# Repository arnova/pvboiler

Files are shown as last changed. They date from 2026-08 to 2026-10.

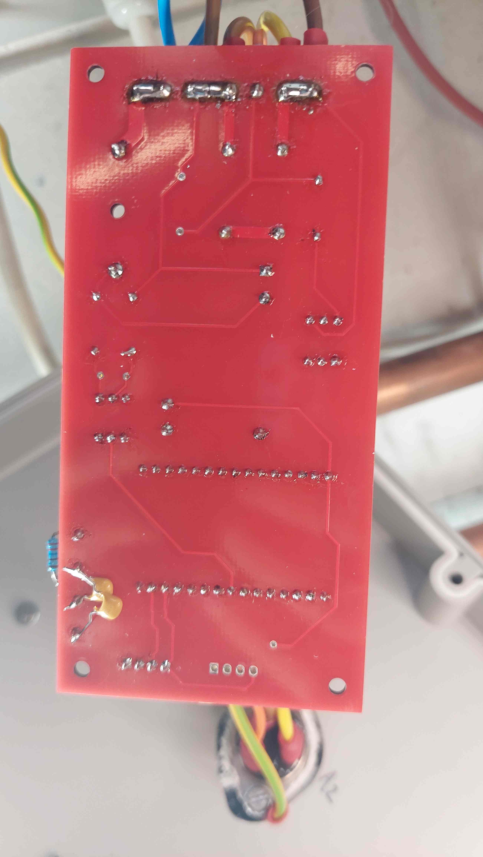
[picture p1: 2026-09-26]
pictures/pvboiler_pcb_rev0_back.jpg

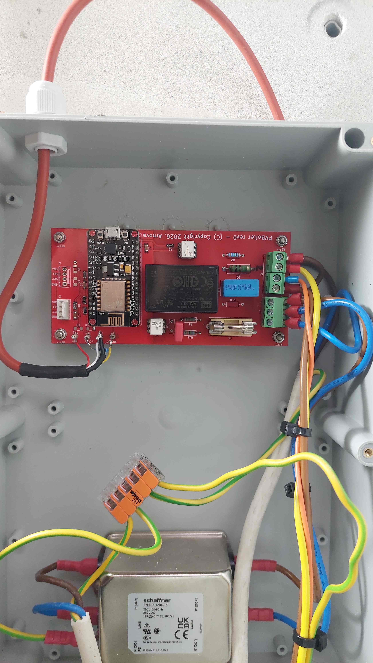
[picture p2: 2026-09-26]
pictures/pvboiler_pcb_rev0_in_enclosure.jpg

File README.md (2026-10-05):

# Open-source ESP PV-Boiler Controller

> ⚠️ **WARNING: HAZARDOUS VOLTAGES**
>
> This project is provided "as-is" and is to be used entirely at your own risk! The hardware is connected to the mains and involves voltages that may be lethal. Only build, install and service it if you are qualified to work on mains equipment, and always disconnect it from the mains before opening the enclosure.
>
> - The ESP/low-voltage side of the controller is galvanically isolated from the mains. Nevertheless, treat everything as live and dangerous!
> - Mount the controller in a closed plastic enclosure and earth the heatsink properly to the mains ground.
> - Only connect the controller to a correctly fused circuit.
> - The boiler's own thermostat and thermal cutoff must remain in the heating circuit. This controller is not a substitute for over-temperature protection!

This project is a complete hardware, firmware & software solution to turn your "dumb" electronic domestic hot water boiler into a smart **PV-Boiler**. It aims to optimize the amount of surplus solar electricity that can be stored in a boiler as hot water using as little grid power as possible.

Most other solutions use SSR modules for power control. This design uses a (BTA25/BTA40) **triac** for power control to enable **phase-angle control**, which allows for more accurate power control than with a normal SSR.

The hardware was designed using **KiCAD**, and the software uses **MQTT** for communication, targeted to be used with **Home Assistant**. The hardware and firmware were developed for a NodeMCU v2 (Amica) ESP8266 module, but should in principle work with any ESP8266 or ESP32 board. Obviously, ESP boards with alternative form factors and/or pinouts cannot be directly fitted on the PCB but should be connected using wires, and you may need to modify platformio.ini and the GPIO definitions in include/system.h for your specific ESP board.

## Features

- Home Assistant (MQTT) support
- Phase angle control (default) or SSR dim style
- Configuration via USB serial connection or network terminal connection (port 8000)
- OTA updates (e.g. via PlatformIO)
- Operating modes: automatic power budget mode (using e.g. P1/HA information), (manual) power percentage mode, boost mode (100% power) and off mode. The mode can be dynamically changed using MQTT
- Support for an optional one-wire DS18B20 temperature sensor (probe) for sensing the boiler's internal temperature
- Support for an optional OLED 128×64 screen to display output power/percentage and connection status
- The controller has a network watchdog. If there hasn't been any MQTT traffic to the controller for a while (e.g. when the network fails), the output will automatically decrease to 0% instead of being stuck on the last value. This behaviour can be disabled/configured with the `netwdt` and `netwdr` commands.

## Planned features & improvements

- Automatic legionella prevention using an external one-wire temperature sensor. Currently boost mode can be used for external (e.g. using Home Assistant) legionella prevention control until implemented in firmware
- Improve control loop for budget logic mode
- Standalone support to directly interface with MQTT P1 providers like DSMR Reader
- New PCB design to fit a (dual-core) ESP32-DevKit module

## Known issues

- During development it turned out that due to the ESP8266's single-core architecture WiFi interferes with accurate interrupt timing, causing problems with zero-cross detection and triac gate firing. Mitigations are in place but they can't completely fix the issue. Therefore for new designs it's recommended to use an ESP board with a dual-core ESP32-S3, ESP32-WROOM or ESP32-Wrover. Note that single-core ESP32 variants (e.g. ESP32-C3, ESP32-S2) share the ESP8266's limitation.

## Electromagnetic compatibility

Phase-angle control inherently generates harmonics and electromagnetic interference, because the triac switches the load on part-way through each mains half-cycle. The design includes an RC snubber across the triac and a 2-stage mains filter to limit this. Although such mains filters are expensive, do not omit them: consider the filter mandatory. Depending on your country and installation, regulations on conducted emissions and flicker (e.g. the EN 61000-3 series in the EU) may still apply to the complete installation, so check them before putting the device into permanent use.

## Hardware Assembly Hints

1. In the pictures-folder of this project you can find photos of my assembled enclosure which can be used as a guideline to build your own device
2. Use a sufficiently sized heatsink with a little thermal compound for mounting the BTA-triac. Generally it is recommended to use a heatsink with a thermal resistance better than 1.0 °C/W when using a ~2500 W boiler. Don't forget to connect the heatsink to the mains ground for safety! You should also use triacs with an electrically insulated tab, like the BTA-type triacs in the design
3. Around some power traces the mask has been intentionally left out. You should solder these traces with extra solder to reduce the power losses due to trace resistance
4. It is recommended to use 1.5 mm² flexible wires for internal wiring
5. When using a one-wire DS18B20 temperature sensor (probe) there are a few things you must adhere to make it work properly. Its supply should be connected to the board's +5V (not +3.3V), and the cable's ground shield should be connected to the (digital) low-voltage ground (NOT the mains ground) of the board. Most (sealed) temperature probes use a metal probe housing which is connected to the cable shield. Since this may short to the mains ground and introduce (switching) noise into the system, it should be isolated. The easiest way to accomplish this is using some shrink-tube
6. The electronics are designed for ~230 VAC grids. For other (lower) grid voltages some resistors (R1, R2, R11) need to be modified
7. The controller can only be connected directly to the normal mains connections of "dumb" hot water boilers. Boilers featuring any kind of (digital) electronics (except for an analog thermostat) require a modification of the boiler's internal wiring, see [Boilers with built-in electronics](#boilers-with-built-in-electronics)

## Boilers with built-in electronics

For boilers with (digital) electronics the controller cannot be connected to the boiler's normal mains connections. Instead, the controller must be placed in series with the boiler's heating element. This requires modifying the boiler's internal wiring:

1. Disconnect the boiler from the mains and make sure it cannot be switched on accidentally.
2. Of the 2 wires of the (internal) heating element(s), identify the one that is connected to the (safety) thermostat. This wire, and therefore the thermostat, must remain untouched.
3. Cut the other wire (the one NOT connected to the thermostat) in two. Connect only the end that goes to the heating element to the controller's TRIAC-L terminal.
4. Power the controller in one of these ways:
   - **Recommended: from the cut wire.** Connect the other cut end (the one coming from the boiler) to the controller's MAINS-L terminal, and connect the controller's MAINS-N terminal to the boiler's N (the connection the thermostat-side element wire returns to). The controller then only needs this one additional N connection. Because the controller takes its L from the same wire that used to feed the element, the L/N polarity pitfall of the separate feed option is avoided, which makes this option much more fool-proof. The cut end goes directly to the boiler's L input and is therefore permanently live; verify this with a multimeter before connecting.
   - **Separate feed.** Connect the controller's MAINS-L and MAINS-N terminals to the boiler's mains L and N, and properly insulate the unused cut end. Make sure the boiler's mains L/N connections are such that the controller's MAINS-L is the same "L" that used to feed the cut wire. Otherwise you create a short between the mains N and L.

Wiring diagram for the recommended power option

Things to be aware of:

- The separate feed option is only suitable for a fixed (hard-wired) installation with verified polarity. Do **not** use it with a reversible plug (e.g. Schuko) where L and N are undefined. Always verify L and N with a multimeter.
- The boiler's own electronics may react unexpectedly to the modification (e.g. by reporting a fault when the element is not powered). This is boiler-dependent.
- Modifying a boiler's internal wiring may void its warranty and, depending on your country, may need to be performed by a qualified electrician.

Only do this when you have sufficient confidence you understand what you are doing!

## First Time Use

1. Flash the ESP firmware using PlatformIO. The initial flash needs to be performed using the USB serial connection, with one of the `usb-xxxxx` (`usb-esp8266` or `usb-esp32`) PlatformIO-environments: `pio run -e usb-xxxxx -t upload`. You may need to customize `platform` and `board` in your `platformio.ini` for your specific ESP board first.
2. After the initial flash, future firmware updates can be done over-the-air (OTA) with one of the `ota-xxxxx` (`ota-esp8266` or `ota-esp32`) PlatformIO-environments: `pio run -e ota-xxxxx -t upload`. Note that you *may* need to substitute the controller's IP address for `pvboiler.local` in `upload_port` of the relevant `ota-xxxxx` environment in case mDNS is not available in your network (or it's failing somehow).
3. Connect to the microcontroller's terminal interface, either via the USB connection or a socket connection to the device's IP at port 8000, using a terminal program (e.g. PuTTY). The network terminal is plain-text and also gives access to the stored WiFi and MQTT credentials, so only use it on a network you trust.
4. In the command terminal, `help` (+ `Enter`) will show all available commands with their descriptions. Initially, these operations must be performed:
   - Reset all settings to default with the `factoryreset`-command.
   - Set your WiFi network SSID with the `ssid`-command, providing the name of your network as an argument.
   - Set your WiFi network password with the `pass`-command, providing your network's security password as an argument. You may provide a zero-length value when your network requires no password.
   - Set your MQTT server IP with the `serverip`-command, providing the server IP as an argument.
   - Set your MQTT server username with the `mqttuser`-command. You may provide a zero-length value when your server requires no username.
   - Set your MQTT server password with the `mqttpass`-command. You may provide a zero-length value when your server requires no password.
   - Set boiler power rating with the `boiler`-command, providing the power rating of your boiler as an argument (the factory default is 2500 W).

> **Notes**
>
> - Only change other settings when you understand what they do!
> - When using budget logic mode, you must regularly (at least at 5-second intervals is recommended) tell the PvBoiler controller how much "budget" (= excess solar PV electricity) is available, e.g. from Home Assistant. A sample automation for Home Assistant can be found in the `home assistant` folder.

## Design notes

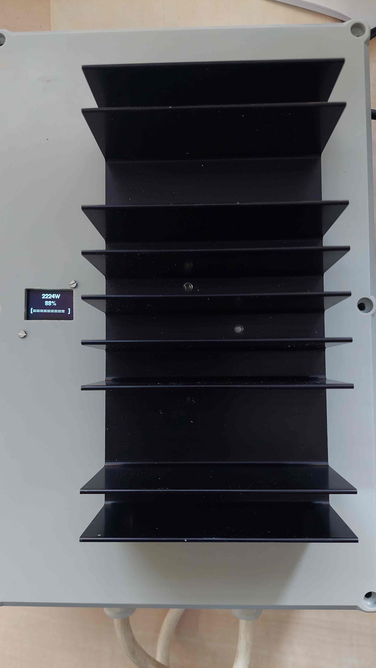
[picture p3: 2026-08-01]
pictures/pvboiler_outside.jpg

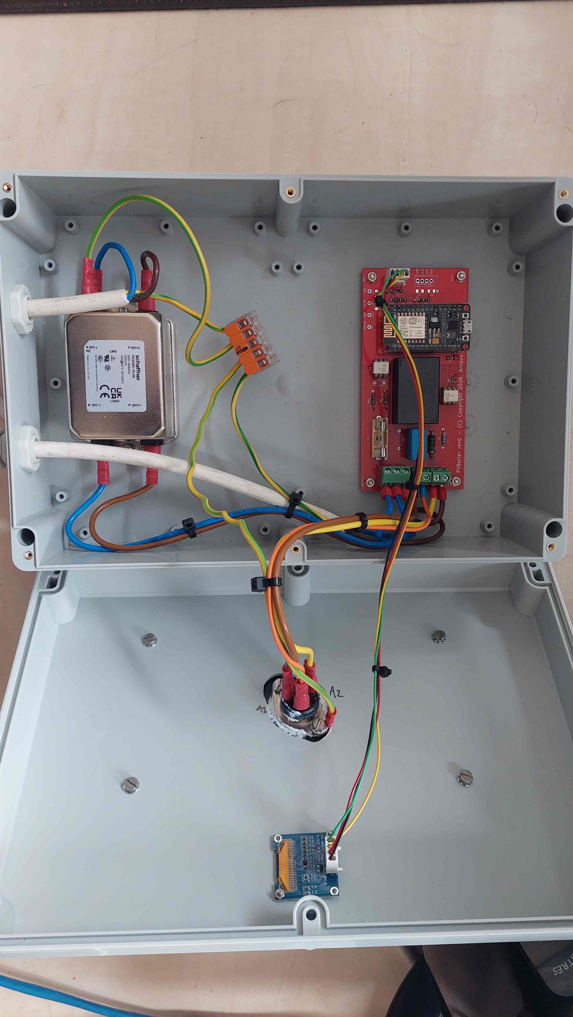
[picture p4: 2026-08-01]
pictures/pvboiler_inside2.jpg

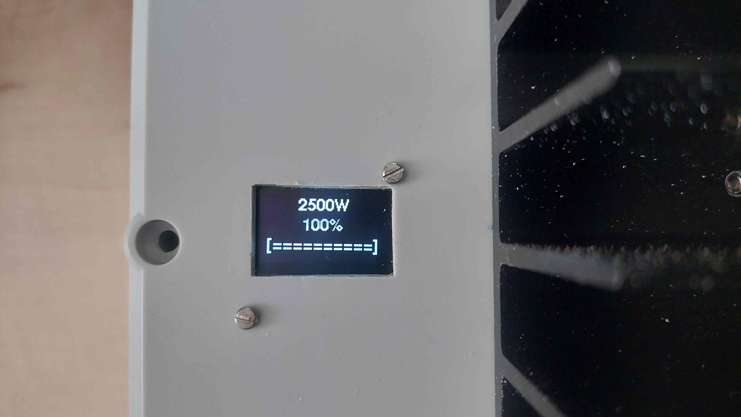
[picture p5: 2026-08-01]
pictures/pvboiler_oled.jpg

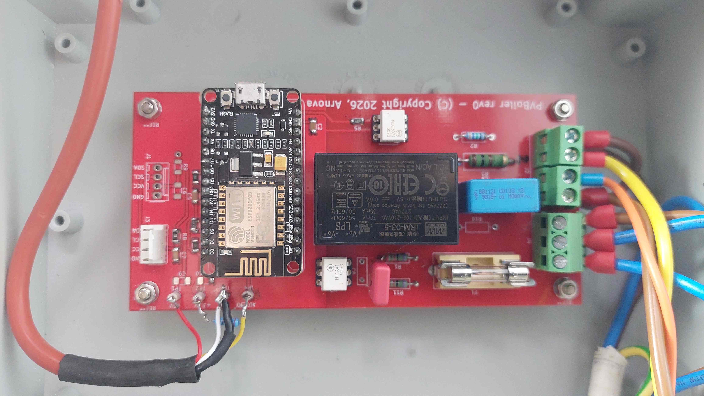
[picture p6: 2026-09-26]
pictures/pvboiler_pcb_rev0_front.jpg

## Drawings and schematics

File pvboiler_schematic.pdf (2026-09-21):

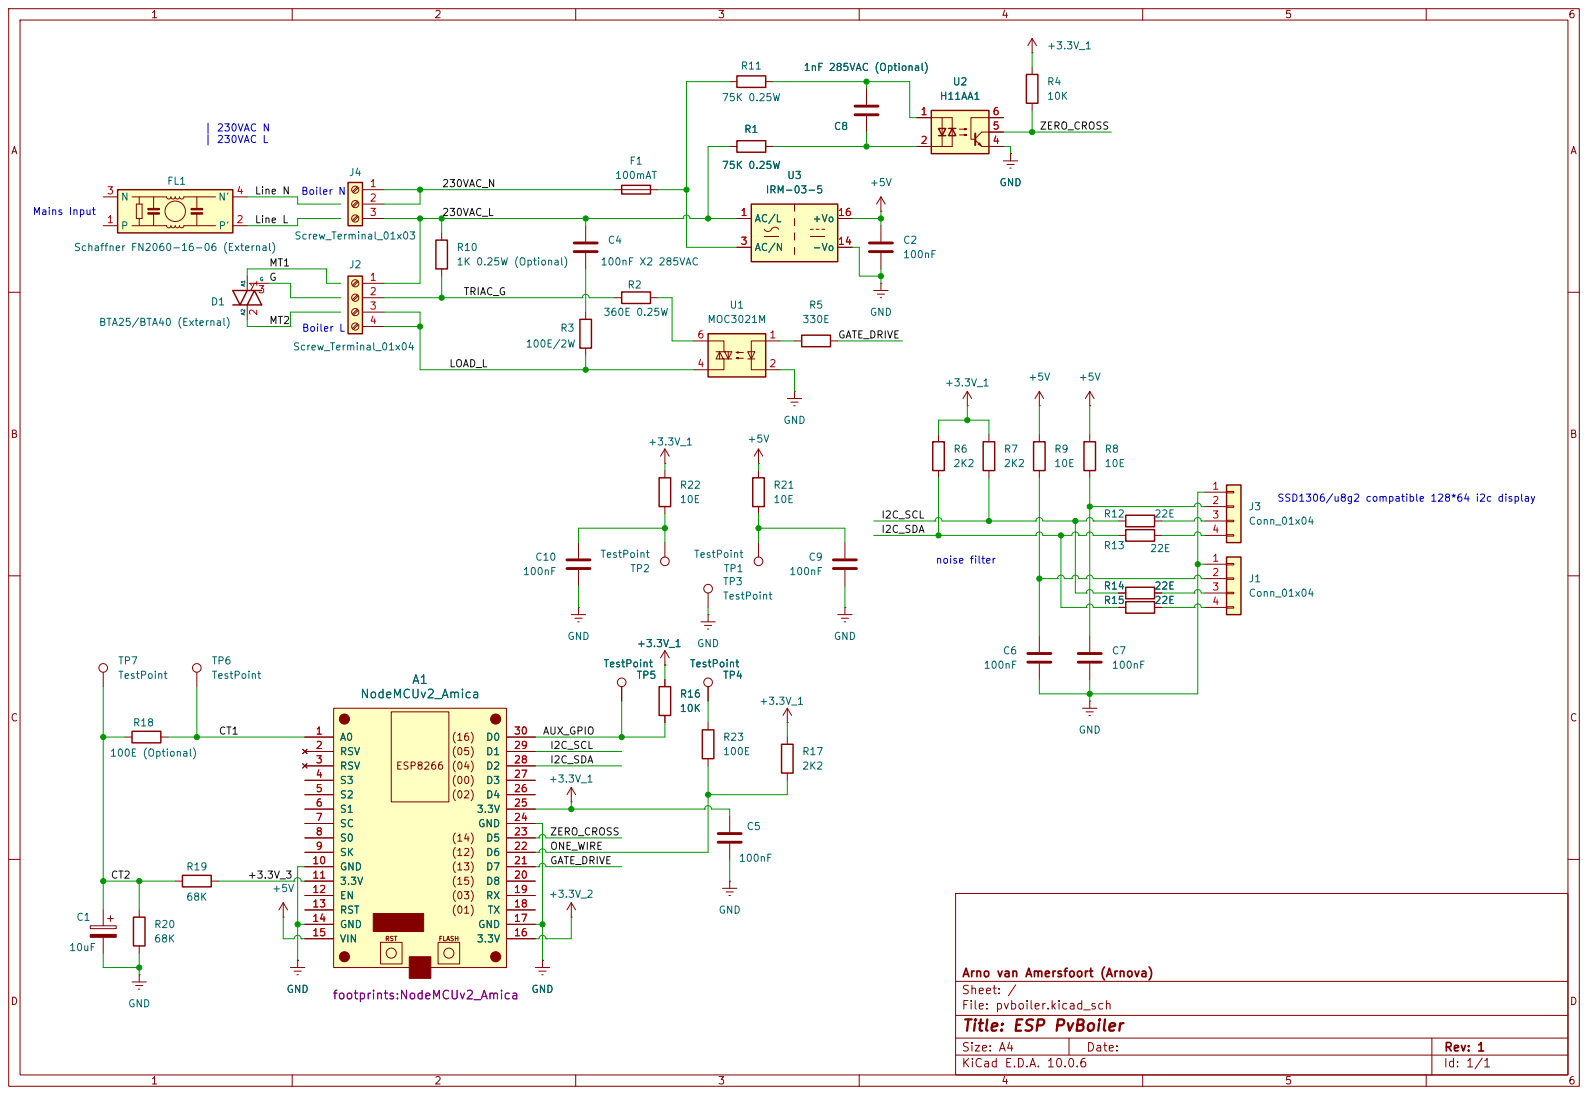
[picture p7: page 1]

Arno van Amersfoort (Arnova) +3.3V_2

Size: A4 | Rev: 1
KiCad E.D.A. 10.0.6 | Id: 1/1

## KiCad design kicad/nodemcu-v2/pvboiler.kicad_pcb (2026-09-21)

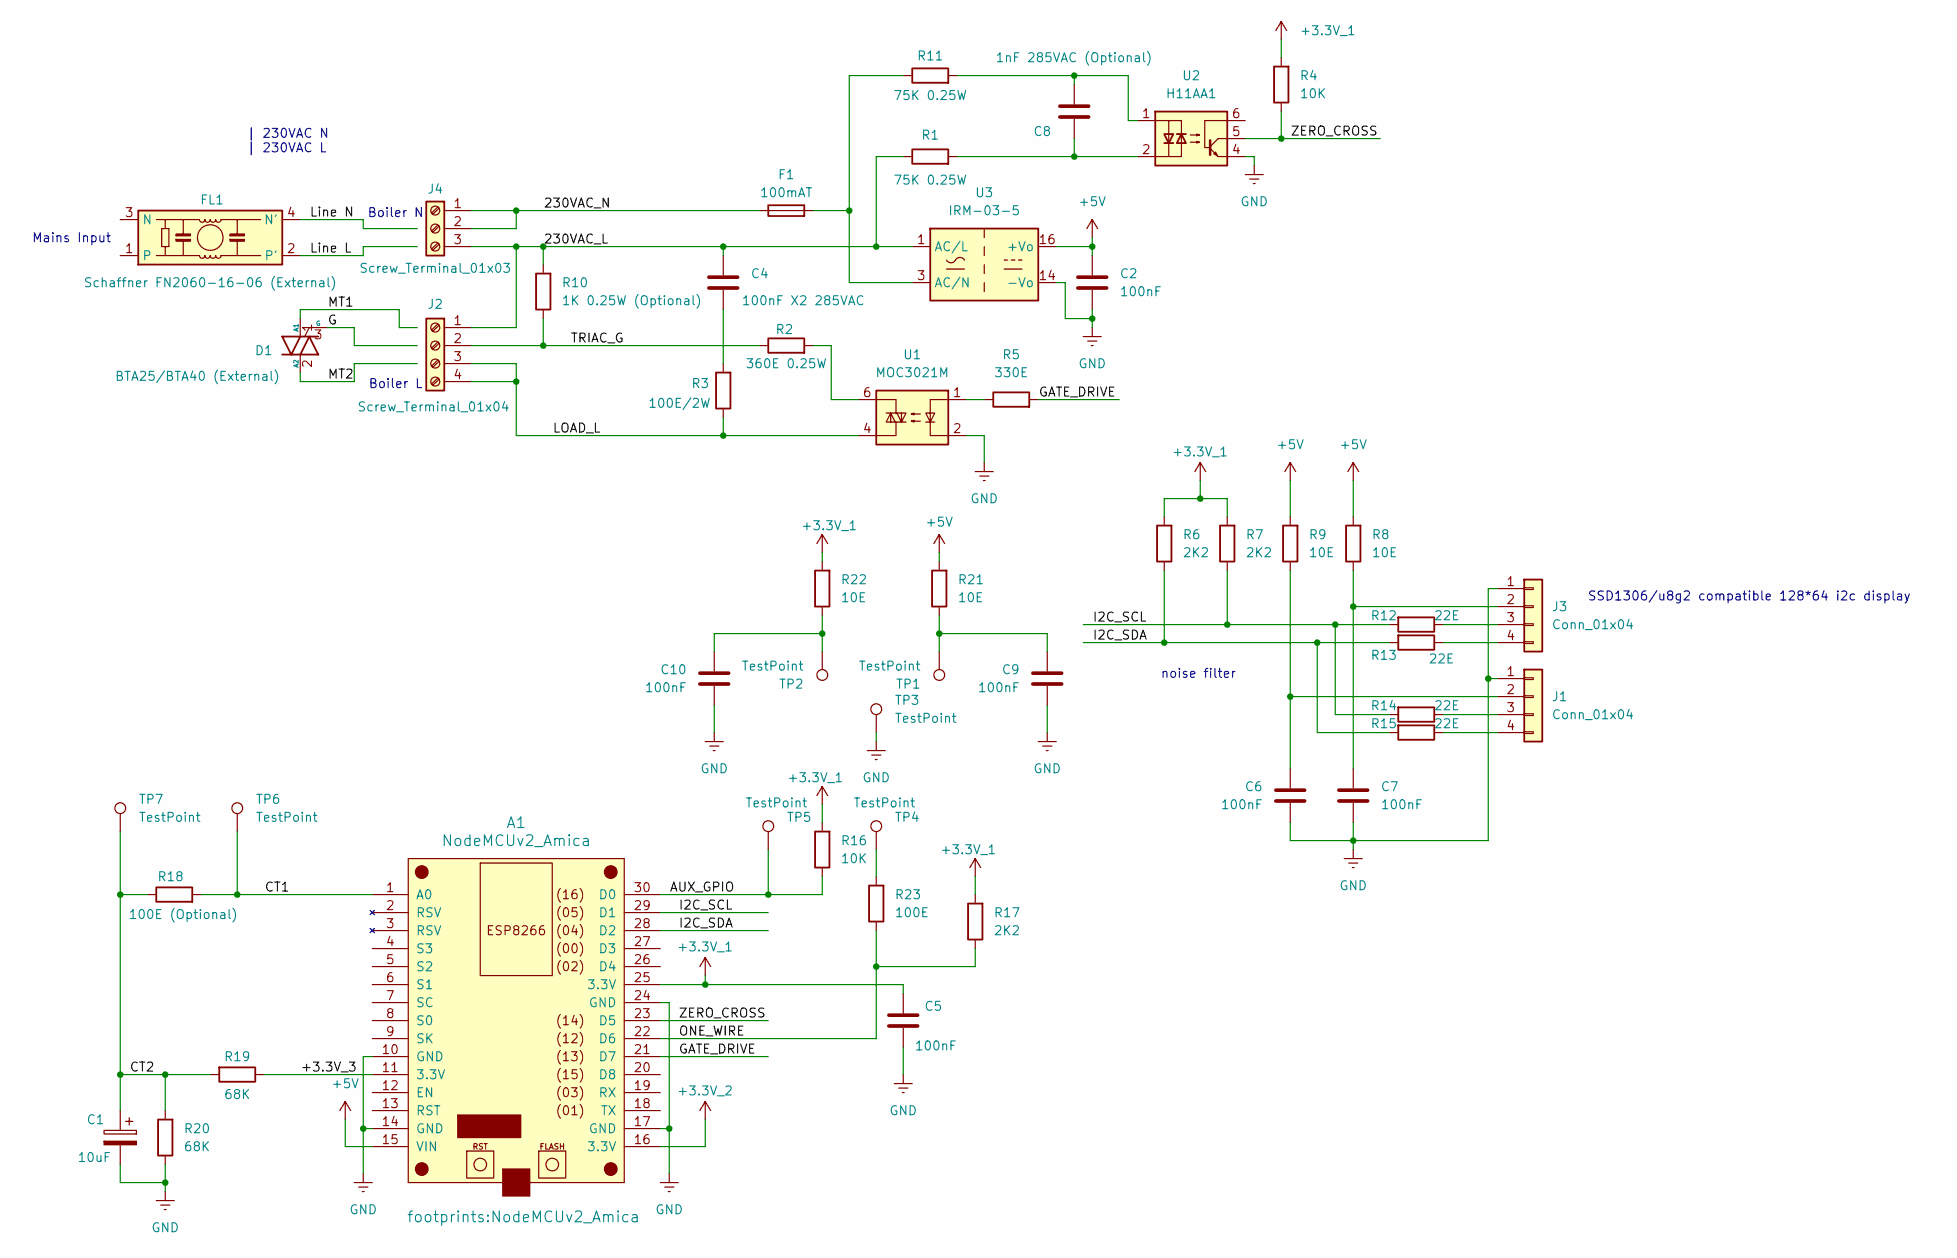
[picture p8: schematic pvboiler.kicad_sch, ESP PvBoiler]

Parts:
A1: NodeMCUv2_Amica
C1: 10uF; CP_EIA-3216-18_Kemet-A_HandSolder
C2, C5, C6, C7, C9, C10: 100nF; C_1206_3216Metric_Pad1.33x1.80mm_HandSolder
C4: 100nF X2 285VAC; C_Rect_L18.0mm_W8.0mm_P15.00mm_FKS3_FKP3
C8: 1nF 285VAC (Optional); C_Rect_L10.0mm_W4.0mm_P7.50mm_MKS4
D1: BTA25/BTA40 (External); PLCC-44_16.6x16.6mm_P1.27mm
F1: 100mAT; Fuseholder_Cylinder-5x20mm_Schurter_0031_8201_Horizontal_Op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
FL1: Schaffner FN2060-16-06 (External); Filter_FILTERCON_1FPxx
J1, J3: Conn_01x04; Molex_KK-254_AE-6410-04A_1x04_P2.54mm_Vertical
J2: Screw_Terminal_01x04; TerminalBlock_Phoenix_MKDS-1,5-4-5.08_1x04_P5.08mm_Horizont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
J4: Screw_Terminal_01x03; TerminalBlock_Phoenix_MKDS-1,5-3-5.08_1x03_P5.08mm_Horizont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
R1, R11: 75K 0.25W; R_Axial_DIN0207_L6.3mm_D2.5mm_P10.16mm_Horizontal
R2: 360E 0.25W; R_Axial_DIN0207_L6.3mm_D2.5mm_P10.16mm_Horizontal
R3: 100E/2W; R_Axial_DIN0414_L11.9mm_D4.5mm_P15.24mm_Horizontal
R4, R16: 10K; R_1206_3216Metric
R5: 330E; R_1206_3216Metric
R6, R7, R17: 2K2; R_1206_3216Metric
R8, R9, R21, R22: 10E; R_1206_3216Metric
R10: 1K 0.25W (Optional); R_Axial_DIN0207_L6.3mm_D2.5mm_P10.16mm_Horizontal
R12, R13, R14, R15: 22E; R_1206_3216Metric
R18: 100E (Optional); R_1206_3216Metric
R19, R20: 68K; R_1206_3216Metric
R23: 100E; R_1206_3216Metric
TP1, TP2, TP3, TP4, TP5, TP6, TP7: TestPoint; TestPoint_THTPad_D2.5mm_Drill1.2mm
U1: MOC3021M; DIP-6_W7.62mm
U2: H11AA1; DIP-6_W7.62mm
U3: IRM-03-5; Converter_ACDC_MeanWell_IRM-03-xx_THT

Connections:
+3.3V_1: A1.25 (3.3V), C5.1, R4.2, R6.2, R7.2, R16.2, R17.2, R22.2
+3.3V_2: A1.16 (3.3V)
+5V: A1.15 (VIN), C2.1, R8.2, R9.2, R21.2, U3.16 (+Vo)
/230VAC_L: C4.2, J2.1, J4.3, R1.1, R10.2, U3.1 (AC/L)
/230VAC_N: F1.1, J4.1, J4.2
/+3.3V_3: A1.11 (3.3V), R19.1
/AUX_GPIO: A1.30 (D0), R16.1, TP5.1 (1_1)
/CT1: A1.1 (A0), R18.2, TP6.1 (1_1)
/CT2: C1.1, R18.1, R19.2, R20.2, TP7.1 (1_1)
/GATE_DRIVE: A1.21 (D7), R5.2
/I2C_SCL: A1.29 (D1), R7.1, R12.2, R14.2
/I2C_SDA: A1.28 (D2), R6.1, R13.2, R15.2
/LOAD_L: J2.3, J2.4, R3.1, U1.4
/ONE_WIRE: A1.22 (D6), R17.1, R23.1
/TRIAC_G: J2.2, R2.1, R10.1
/ZERO_CROSS: A1.23 (D5), R4.1, U2.5
GND: A1.10 (GND), A1.14 (GND), A1.17 (GND), A1.24 (GND), C1.2, C2.2, C5.2, C6.2, C7.2, C9.2, C10.2, J1.1, J3.1, R20.1, TP3.1 (1_1), U1.2, U2.4, U3.14 (-Vo)
unnamed: C4.1, R3.2
unnamed: C8.1, R11.2, U2.1
unnamed: C8.2, R1.2, U2.2
unnamed: C9.1, R21.1, TP1.1 (1_1)
unnamed: C10.1, R22.1, TP2.1 (1_1)
unnamed: C6.1, J1.2, R9.1
unnamed: J1.3, R14.1
unnamed: J1.4, R15.1
unnamed: C7.1, J3.2, R8.1
unnamed: J3.3, R12.1
unnamed: J3.4, R13.1
unnamed: R2.2, U1.6
unnamed: R5.1, U1.1
unnamed: R23.2, TP4.1 (1_1)
unnamed: F1.2, R11.1, U3.3 (AC/N)

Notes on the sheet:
SSD1306/u8g2 compatible 128*64 i2c display
| 230VAC N | 230VAC L
Boiler N
noise filter
Boiler L
Mains Input

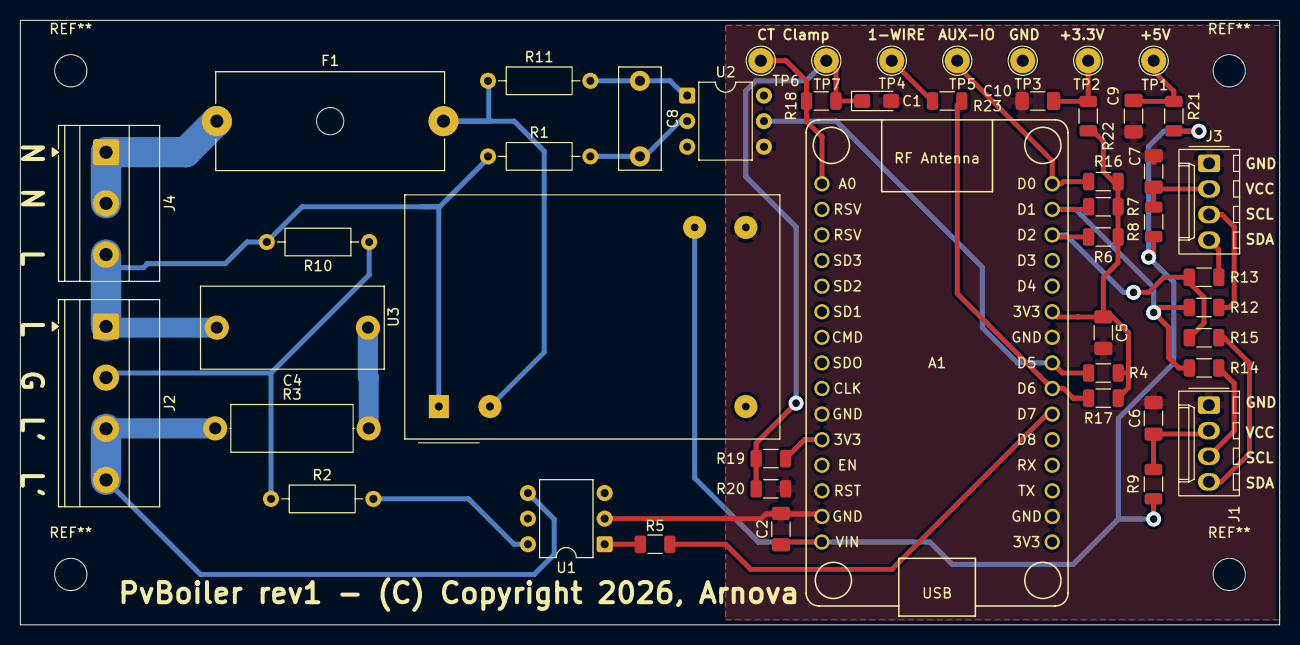
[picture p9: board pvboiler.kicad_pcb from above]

Board: 2 copper layers, 125.0 x 60.0 mm, 48 parts (0 on the bottom side), 31 nets.

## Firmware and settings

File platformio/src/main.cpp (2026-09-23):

/*
  ESP PV-Boiler - ESP Controlled PV Boiler
  Last update: September 21, 2026
  (C) Copyright 2026 by Arno van Amersfoort
  Web                   : https://github.com/arnova/pvboiler
  Email                 : a r n o DOT v a n DOT a m e r s f o o r t AT g m a i l DOT c o m
                          (note: you must remove all spaces and substitute the @ and the . at the proper locations!)
  ----------------------------------------------------------------------------------------------------------------------
  This program is free software; you can redistribute it and/or
  modify it under the terms of the GNU General Public License
  version 2 as published by the Free Software Foundation.

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
  You should have received a copy of the GNU General Public License
  along with this program; if not, write to the Free Software
  Foundation, Inc., 59 Temple Place - Suite 330, Boston, MA  02111-1307, USA.
  ---------------------------------------------------------------------------------------------------------------------- 
*/

#include <Arduino.h>
#include <EEPROM.h>

#include "Terminal.h"
#include "util.h"
#include "App.h"
#include "system.h"

// Application global instance
CApp g_app;

// Interrupt generated when crossing zero in either direction
void IRAM_ATTR ZeroCrossISR()
{
  g_app.ZeroCrossHandler();
}


// Timer interrupt for triggering triac gate
void IRAM_ATTR TriacTimerISR()
{
  g_app.TriacGateHandler();
}


void MqttCallback(char* topic, byte *payload, const unsigned int length)
{
  const size_t iLen = strlen(g_app.GetNetwork().GetHostName());
  if (strncmp(topic, g_app.GetNetwork().GetHostName(), iLen) != 0 ||
      strlen(topic) < iLen + 2)
    return; // Hostname mismatch or length too small

#ifdef MQTT_DEBUG
  CTerminal::println("-------new message from broker-----");
  CTerminal::print("topic: ");
  CTerminal::println(topic);
  CTerminal::print("data: ");
  for (unsigned int i = 0; i < length; i++)
  {
    CTerminal::print((char) payload[i]);
  }
  CTerminal::println("");
#endif
  //float fVal;
  //const bool bValidFloat = BytesToFloat(payload, length, fVal);

  int32_t iVal;
  const bool bValidInt = bytes_to_int32(payload, length, &iVal);

  char strVal[32] = { 0 };
  memcpy(strVal, payload, (length < sizeof(strVal)) ? length : sizeof(strVal) - 1);

  // Get rid of host prefix
  char* subTopic = topic + iLen;

  if (STRIEQUALS(subTopic, "/" MQTT_SET_POWER_BUDGET "/set"))
  {
    if (bValidInt)
    {
      g_app.GetPvBoiler().SetPowerBudget(iVal);
    }
    else
    {
      CMqttClient::PrintDataError();
    }
  }
  else if (STRIEQUALS(subTopic, "/" MQTT_SET_POWER_PERCENTAGE "/set"))
  {
    if (bValidInt && iVal >=0 && iVal <= 100)
    {
      g_app.GetPvBoiler().SetPowerPercentage(iVal);
    }
    else
    {
      CMqttClient::PrintDataError();
    }
  }
  if (STRIEQUALS(subTopic, "/" MQTT_SET_MODE "/set"))
  {
    if (strcasecmp(strVal, "Budget") == 0)
    {
      g_app.GetPvBoiler().SetMode(CPvBoiler::MODE_BUDGET);
    }
    else if (strcasecmp(strVal, "Percentage") == 0)
    {
      g_app.GetPvBoiler().SetMode(CPvBoiler::MODE_PERCENT);
    }
    else if (strcasecmp(strVal, "Off") == 0)
    {
      g_app.GetPvBoiler().SetMode(CPvBoiler::MODE_OFF);
    }
    else if (strcasecmp(strVal, "Boost") == 0)
    {
      g_app.GetPvBoiler().SetMode(CPvBoiler::MODE_BOOST);
    }
    else
    {
      CMqttClient::PrintDataError();
    }
  }

  // Got a message so network is still ok:
  g_app.GetPvBoiler().TrigNetworkWatchdog();
}


void setup()
{
  EEPROM.begin(512); // Reserve room for eeprom settings

  randomSeed(micros());

  // Outputs
#ifdef STATUS_LED
  pinMode(STATUS_LED, OUTPUT);
#endif

  pinMode(TRIAC_OUTPUT, OUTPUT);
  digitalWrite(TRIAC_OUTPUT, LOW);

  pinMode(ZERO_CROSS_INPUT, INPUT_PULLUP);

  TERM_SERIAL.begin(BAUD_RATE);
  TERM_SERIAL.setTimeout(2000);

  // Init g_app instance
  g_app.Init();

  // Setup the MQTT client callback
  g_app.GetNetwork().GetMqttClient().setCallback(MqttCallback);

#ifdef ESP8266
  timer1_isr_init();
  timer1_attachInterrupt(TriacTimerISR);
  timer1_enable(TIM_DIV1, TIM_EDGE, TIM_SINGLE);   // TIM_SINGLE = single shot
#else // ESP32
  hw_timer_t* hTriacTimer = timerBegin(0, 80, true); // timer 0, /80 prescaler of 80 MHz APB → 1 MHz tick
  timerAttachInterrupt(hTriacTimer, &TriacTimerISR, true);
  g_app.SetTimerHandle(hTriacTimer);
#endif

  attachInterrupt(digitalPinToInterrupt(ZERO_CROSS_INPUT), ZeroCrossISR, CHANGE);

    // Allow the hardware to sort itself out
  delay(1500);

  // Have the terminal start with a newline
  CTerminal::println("");

  // Print out version info
  CTerminal::println(FPSTR(VER_STR_P));
}


void loop()
{
  g_app.Loop();
}

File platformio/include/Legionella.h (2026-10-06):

#pragma once
#ifndef LEGIONELLA_H
#define LEGIONELLA_H

#include "system.h"

#ifndef DANGER_ZONE_LOW_TEMPERATURE
#define DANGER_ZONE_LOW_TEMPERATURE   20.0f // Celsius. FIXME: Should be configurable
#endif

#ifndef DANGER_ZONE_HIGH_TEMPERATURE
#define DANGER_ZONE_HIGH_TEMPERATURE  45.0f // Celsius. FIXME: Should be configurable
#endif

#ifndef DANGER_ZONE_DWELL_LIMIT_DAYS
#define DANGER_ZONE_DWELL_LIMIT_DAYS  7     // Days. FIXME: Should be configurable
#endif

#ifndef DISINFECT_RUN_TIME_MINUTES
#define DISINFECT_RUN_TIME_MINUTES    15    // Minutes. FIXME: Should be configurable
#endif

#ifndef DISINFECT_TEMPERATURE
#define DISINFECT_TEMPERATURE         60.0f // Celcius. FIXME: Should be configurable
#endif


class CLegionella
{
  public:
    CLegionella() {}; // Empty ctor
    ~CLegionella() {}; // Empty dtor

    void Reset() { m_iSecondsPassedSinceLastDisinfect = 0; m_iDisinfectRuntimeSeconds = 0; m_iSecondsInDangerZone = 0; m_bMustDisinfect = false; };
    void Loop();
    void UpdateTemperature(const float fTemperature) { m_fTemperature = fTemperature; };

    void SetSecondsPassedSinceLastDisinfect(const uint32_t iTime) { m_iSecondsPassedSinceLastDisinfect = iTime; }; // FIXME: m_iSecondsInDangerZone?

    const uint32_t GetHoursPassedSinceLastDisinfect() { return m_iSecondsPassedSinceLastDisinfect / 3600; };
    const uint32_t GetDisinfectRunTimeSeconds() { return m_iDisinfectRuntimeSeconds; };
    const uint32_t GetHoursInDangerZone() { return m_iSecondsInDangerZone / 3600; };
    bool MustDisinfect() { return m_bMustDisinfect; };

  private:
    uint32_t m_iSecondsPassedSinceLastDisinfect; // s
    uint32_t m_iDisinfectRuntimeSeconds; // s
    uint32_t m_iSecondsInDangerZone; // s

    float m_fTemperature = -1.0f;
    bool m_bMustDisinfect = false;
};
#endif // LEGIONELLA_H

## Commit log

2026-04-23 changed: Implement rising/falling zero cross detection logic for phase correction (delay)
    [main.cpp, system.h]
2026-04-24 added: Support for esp32 as well fixed: Correctly configure platformio for esp8266 nodemcu fixed: Setting output percentage was broken changed: Tweak mqtt naming changed: gpio config for nodemcu chan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
    [main.cpp, system.h]
2026-04-24 fixed: Properly sanity check mqtt set values fixed: Forgot to reenable watchdog check changed: Misc. tweaks
    [main.cpp]
2026-04-24 fixed: triac power percentage to time factor table fixed: Triac angle logic should only execute on first zero cross (rising edge) changed: Lower watchdog recovery time to 1 minute changed: When disab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
    [main.cpp]
2026-04-26 added: SSR style mode (instead of phase-cut)
2026-04-28 changed: Generate 100 uS gate pulse to reduce driver dissipation
2026-04-28 fixed: SSR period count calculation
    [main.cpp, system.h]
2026-04-28 changed: Make gate pulse width 1ms, just in case
2026-05-13 fixed: Typo causing home assistant config topics not to work fixed: Sensor configs were missing changed: Tweaks
    [main.cpp]
2026-05-13 fixed: Power budget may be negative changed: Set boiler power to 2500 (W)
    [main.cpp, system.h]
2026-05-13 fixed: Power budget cap logic was broken
2026-05-13 fixed: PID must regulate power budget to 0% + output should negate input to get a proper percentage value
2026-05-13 fixed: Don't cap (negative) power budget values changed: Ki factor 0.01 -> 0.1
2026-05-13 changed: Adjust PID values for fast eg. cloud tracking
2026-05-14 changed: Get rid of PID and use simpler power diverter algorithm
2026-05-14 changed: Since we need i2c for the future display move gpios to unused spi pins
2026-05-16 changed: We can't fire triac too close to zero-crossing
    [main.cpp, system.h]
2026-05-20 changed: Implement initial i2c SSD1306 display support using U8g2 library
2026-05-28 changed: Swap zero-cross and gate-drive gpios
    [system.h]
2026-07-10 changed: Initial support for control using socket server at TCP port 8080
2026-07-11 changed: Replace some forward declares with object reference calls
    [main.cpp]
2026-07-13 changed: Create static CTermPrint class functions to replace print forward declares
    [Network.cpp, main.cpp]
2026-07-13 changed: Get rid of MqttUtil and replace with MqttClient (PubSubClient derived class) changed: Make mqtt-client object member of network-class
    [Network.cpp]
2026-07-13 fixed: Must always set wifi-connected flag when connected
    [main.cpp]
2026-07-13 fixed: Set dim-style command didn't work fixed: Cosmetics
    [main.cpp]
2026-07-13 fixed: Percentage calculation was broken changed: Use enum typedef for logicmode changed: Cosmetics
    [App.cpp, main.cpp]
2026-07-13 changed: Refactor socket server client handling changed: Refactor some code + cosmetics
2026-07-13 changed: Replace some const char [] variables with PROGMEM/PSTR to reduce RAM use
    [App.cpp, main.cpp, system.h]
2026-07-15 fixed: Socket client output was broken
    [App.cpp]
2026-07-15 fixed: WiFi connected was no longer detected
    [App.cpp]
2026-07-15 changed: Improve logging changed: Replace all Serial. instances with TERM_SERIAL.
    [App.cpp, Network.cpp, main.cpp]
2026-07-15 fixed: WiFi reconnect didn't work
    [App.cpp, Network.cpp]
2026-07-15 fixed: ISRs on ESP8266 cannot call non-inlined/RAM_ATTR functions changed: Refactor some code
    [App.cpp, main.cpp]
2026-07-16 fixed: Network (re)connection logic
    [Network.cpp]
2026-07-17 fixed: Must keep wifi timeout timer reset when connected fixed: Must only flag wifi not connected after timeout changed: Misc. tweaks
    [Network.cpp]
2026-07-17 fixed: Stop socket server when disconnecting fixed: Perform ArduinoOTA & MDNS init when wifi is actually connected
    [Network.cpp]
2026-07-17 changed: Rename some commands for clarity fixed: power_out was missing in status changed: Misc. tweaks in info/status
2026-07-17 changed: Move ArduinoOTA handling from CApp to CNetwork changed: Misc. tweaks
2026-07-17 fixed: m_bWifiConnected-flag should always be cleared in InitWifi() else we won't detect reconnects properly
    [Network.cpp]
2026-07-17 changed: Make socket server setup from InitWifi() to Network-Loop
2026-07-18 changed: Implement power indicator
2026-07-18 fixed: Phase cutting / zero-crossing logic didn't work properly due DigitalRead() returning incorrect value due to non Schmitt-triggered zero cross pulse from optocoupler
    [App.cpp, system.h]
2026-07-18 fixed: Must update MQTT config when logic-mode is changed changed: Move CApp::MqttPublish to CPVBoiler:MqttPublishConfigCApp changed: Make min/max/step optional for Mqtt number configs changed: Clean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
    [App.cpp, main.cpp]
2026-07-18 renamed: Phate-cut -> phase-angle
2026-07-19 changed: Implement reset command
    [App.cpp]
2026-07-19 fixed: ArduinoOTA on ESP8266
    [Network.cpp]
2026-07-20 fixed: Possible crash on start. Initializing stuff in global instance constructor is a bad idea
    [App.cpp, Network.cpp, main.cpp]
2026-07-20 changed: Use box entry instead of slider for value numeric values in home assistant fixed: Budget power was limited to 0-100
2026-07-20 fixed: Setting budget using mqtt was broken
    [main.cpp]
2026-07-21 fixed: Output percentage clamping was broken in budget logic mode
2026-07-21 changed: Don't use box input for power percentage control
2026-07-21 fixed: Must unpublish unused control values fixed: Sensors can't have /set changed: Refactor MqttClient
    [PvBoiler.h]
2026-07-21 changed: Refactor MqttClient changed: Reorder EEPROM locations added: Implement error clamping incl. command to set it changed: Prefix various commands with "Set" for clarity changed: Only send some 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
    [Network.cpp, PvBoiler.h, system.h]
2026-07-21 changed: Calculate values in CPvBoiler::UpdateTriacPhaseAngle() instead of inside zero-cross isr fixed: Some variables were not used thread-safe added: State class option for PublishSensorConfig() ch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
    [App.cpp, PvBoiler.h, main.cpp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]
2026-07-21 fixed: When dim style is changed to ssr we must unpublish phase-angle sensor config fixed: When updating dim-style, must update mqqt config as well
2026-07-21 fixed: Must update mqtt (control) values when mqtt server (re)connects fixed: Must disconnect from mqtt server when changing ip changed: Small cleanup
    [App.cpp, Network.cpp]
2026-07-21 changed: Improve mqtt (re)connect logic changed: Increase mqtt connect timeout changed: Don't print mqtt debug messages with MQTT_DEBUG disabled
2026-07-21 fixed: SSR period can't be more than 254 fixed: eclamp command was missing in help() changed: Cosmetics in info
    [system.h]
2026-07-21 fixed: Phase angle display changed: Report triac phase angle in ms changed: Refactor some code fixed: Phase-angle missing missing in status command output
    [App.cpp, PvBoiler.h]
2026-07-23 fixed: mqtt device identifiers should be [0] changed: Report f/w version in ha mqtt device info
2026-07-23 fixed: Compiler error on esp32 in CNetwork
    [Network.cpp]
2026-07-23 fixed: esp32 timers are different from esp8266
    [App.cpp, main.cpp, system.h]
2026-07-23 changed: Improve triac calculation logic changed: Implement triac error logic changed: Reset more member variables with reset-command
    [App.cpp, PvBoiler.h, system.h]
2026-07-27 fixed: uint32_t -> uint16_t return value
    [PvBoiler.h]
2026-07-27 changed: Improve scaling for power indicator on ssd1306 display due to non monospace chararacters
2026-07-27 changed: Use floating point internally for calculating current percentage changed: Refactor some related code
2026-07-27 changed: Tweak error gain default/min/max values a bit. The 0.1f default gives oscillation
    [system.h]
2026-07-27 changed: Error clamp should have "%"-power-factor dimension for MQTT
2026-07-27 changed: On init and with errors set period-time to 65535us changed: Rename triac-error to power-error changed: Report power errors on display changed: Detect last zero cross timeouts changed: Also u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
    [App.cpp, PvBoiler.h, system.h]
2026-07-27 changed: Don't reset mqtt timeout timer when wifi is not connected to improve connection speed after wifi connects
    [Network.cpp]
2026-07-27 changed: Get rid of some String uses to prevent heap fragmentation
    [App.cpp, Network.cpp, system.h]
2026-07-27 added: KiCad design files
    [pvboiler-B_Cu.gbl, pvboiler-B_Mask.gbs, pvboiler-B_Paste.gbp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]
2026-07-27 fixed: Logging connection client was broken changed: Cosmetics
    [App.cpp, Network.cpp]
2026-07-27 fixed: Power / percentage on display
    [App.cpp]
2026-07-27 fixed: Web url in main.cpp
    [main.cpp]
2026-07-27 changed: Improve terminal handlng & merge Serial & Socket handling
2026-07-28 changed: Set mqtt update time from 1s to 15s to prevent home assistant from locking up
    [system.h]
2026-07-28 fixed: Reported net period is for rectified 50 Hz so needs to be *2 changed: Also report net frequency
    [system.h]
2026-07-28 changed: Implement blanking in zero cross ISR around gate fireing to prevent false zero cross triggers
    [App.cpp]
2026-07-29 fixed: Power % display in home assistant
2026-07-29 changed: Move some mqtt sensors to diagnostic
2026-07-30 changed: Always add #pragma once to header file, just in case
2026-07-30 added: Missing header info removed: Redundant include
    [Network.cpp]
2026-07-30 changed: Increase opto cap size footprint changed: Pcb version bump to rev1
    [pvboiler-B_Cu.gbl, pvboiler-B_Mask.gbs, pvboiler-B_Paste.gbp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]
2026-08-01 changed: Replace budget margin power with dead zone percentage changed: Make control loop update speed 1s instead of 0.2s changed: Tweak + refactor control loop logic
    [PvBoiler.h, main.cpp, system.h]
2026-08-01 added: Schematic pdf added: Pictures
    [pvboiler.kicad_sch]
2026-08-03 updated: Some tweaks in KiCAD schematic / pcb
    [pvboiler-B_Cu.gbl, pvboiler-B_Mask.gbs, pvboiler-B_Paste.gbp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]
2026-08-05 added: (power) boost command/toggle
2026-08-06 changed: Expose ESP8266 D0 on extra tp
    [pvboiler-B_Cu.gbl, pvboiler-B_Mask.gbs, pvboiler-B_Paste.gbp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]
2026-08-08 changed: Improve error logic
    [App.cpp, PvBoiler.h, system.h]
2026-08-09 fixed: Error flagging logic was still broken
    [PvBoiler.h, system.h]
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2026-08-10 added: MQTT username/password configuration commands fixed: Corruption due to missing null-termination for strings read from eeprom changed: Allow setting no wifi password
    [Network.cpp, system.h]
2026-08-28 added: Budget margin logic changed: Reorder eeprom layout fixed: Unpublish of some budget sensor values changed: Misc. tweaks changed: Version bump to v1.05
    [PvBoiler.h, system.h]
2026-08-29 changed: When a new socket client connect, terminate current connection
2026-08-30 changed: Add (future) CT connection for A0 changed: Improve schematic
    [pvboiler.kicad_pcb, pvboiler.kicad_sch]
2026-09-04 changed: Allow setting separate positive & negative values for error-gain and step-clamp
    [PvBoiler.h, system.h]
2026-09-11 added: Initial support for ds18b20 one-wire temperature sensor
2026-09-11 fixed: Typo causing eeprom gains to be stored incorrectly
    [system.h]
2026-09-15 added: Display temperature on oled screen
2026-09-18 updated: Tweaks in schematic/PCB
    [pvboiler.kicad_pcb, pvboiler.kicad_sch]
2026-09-18 changed: Move temperature line down on display (cosmetic)
2026-09-18 changed: Improve temperature sensor logic + implement error handling/retry
    [PvBoiler.h]
2026-09-19 changed: Improve response for ha switches
2026-09-21 updated: Kicad schematic/pcb
    [pvboiler.kicad_pcb, pvboiler.kicad_sch]
2026-09-21 changed: Implement rolling average for boiler temperature
2026-09-21 updated: Gerbers & schematic pdf
    [pvboiler-B_Cu.gbl, pvboiler-B_Mask.gbs, pvboiler-B_Paste.gbp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]
2026-09-23 changed: Implemented configuration of the hostname to allow the use of multiple devices in the same network
2026-09-23 changed: No point in handling mdns ourselves since it's already managed by ArduinoOTA
2026-09-23 changed: Increase negative step clamp value from 3 to 12%
2026-09-29 changed: Move current KiCAD version to nodemcu-v2 subfolder
    [pvboiler-B_Cu.gbl, pvboiler-B_Mask.gbs, pvboiler-B_Paste.gbp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]
2026-10-01 changed: Implement usb & ota section in platformio.ini to allow switching without touching ini
2026-10-02 changed: Wifi on ESP8266 introduces occasional ISR handling latency, mitigate this by compensating / averaging timing values changed: Improve + refactor power-error detection logic
    [App.cpp, PvBoiler.h, system.h]
2026-10-02 fixed: Small corrections for triac phase angle/factor mqtt/status naming
    [system.h]
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2026-10-04 fixed: Typos in MQTT names
    [PvBoiler.h, system.h]
2026-10-05 changed: Extend mqtt number config with device-class & unit option
2026-10-12 added: Temperature override mqtt control fixed:
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2026-10-12 changed: Improve logic when temperature sensor not detected
2026-10-12 fixed: Some member variables would not update when mqtt server was not connected changed: Only update mqtt values when changed fixed: Typo causing boiler temperature to always update when not sensor 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
2026-10-12 added: New "On" mode to allow maximum power output while still respecting thermostat override (if set)
2026-10-12 changed: Improve temperature (error) handling
2026-10-12 added: Command to set temperature override from terminal
2026-10-12 fixed: Reading operating mode from eeprom was broken fixed: With factory reset also reset mqtt update interval changed: Store temperature override (thermostat) in eeprom changed: On reset, reinit tem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
2026-10-12 changed: Must-disinfect -> Disinfection-required and make it a non-diag binary-sensor changed: thermostat_heating -> thermostat_allows_heating
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2026-10-12 changed: Lower temperature averages to 30 changed: Use averaged value for checking overheating
2026-10-12 fixed: Sometimes sensor values would show unknown value after flash since the values are not longer retained
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2026-10-12 added: Commands to configure thermostat hysteresis, legionella danger-zone temperatures, disinfect interval, run-time & temperature added: Show these settings with info-command and as mqtt diag senso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
2026-10-19 fixed: restartnet didn't reconnect (until WiFi timeout) when SSID/password were unchanged fixed: WiFi connection loss wasn't detected until the reconnect timeout fixed: restartnet result ("OK") was l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
2026-10-22 fixed: Boiler power rating min. mismatch between command and EEPROM load
2026-10-22 fixed: Negative error gain/step clamp commands used positive limits
2026-10-23 fixed: Misleading over temperature protection comment
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2026-10-25 changed: Add controller state sensor (MQTT, CLI & OLED)
    Reports what the controller is actually doing, as opposed to the selected
    mode: off, standby, overheated, sensor fault, legionella heating/holding,
    network timeout, boost, heating to setpoint, setpoint reached, heating on
    surplus, waiting for budget or fixed percentage.
    - State is determined in Update() alongside the output percentage
    - Published as Home Assistant enum sensor "controller_state"
    - Added CMqttClient::PublishEnumSensorConfig()
    - Shown in CLI status and on the OLED temperature screen
    - OLED: title/version screen is now only shown during boot
2026-10-26 changed: Report ip netmask as mqtt diagnostic sensor
2026-10-26 changed: Only show passwords in "info" on the serial terminal, not on the socket terminal
2026-10-26 added: Optional password login for the socket (network) terminal (TERMINAL_PASSWORD) changed: Reorder some defines
2026-10-27 changed: Show passwords in "info" on the socket terminal when login is enabled (TERMINAL_PASSWORD)
2026-10-29 changed: PrintItemValue() accepts an optional suffix and has int/float overloads, so most snprintf() calls in "info" and "status" are gone
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2026-10-29 changed: PrintItemIp() accepts IPAddress instead of uint8_t*, and status also shows the WiFi subnet mask removed: Unused CCommandHandler::FormatIP()

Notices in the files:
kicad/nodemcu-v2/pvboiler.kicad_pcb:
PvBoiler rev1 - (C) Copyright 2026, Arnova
